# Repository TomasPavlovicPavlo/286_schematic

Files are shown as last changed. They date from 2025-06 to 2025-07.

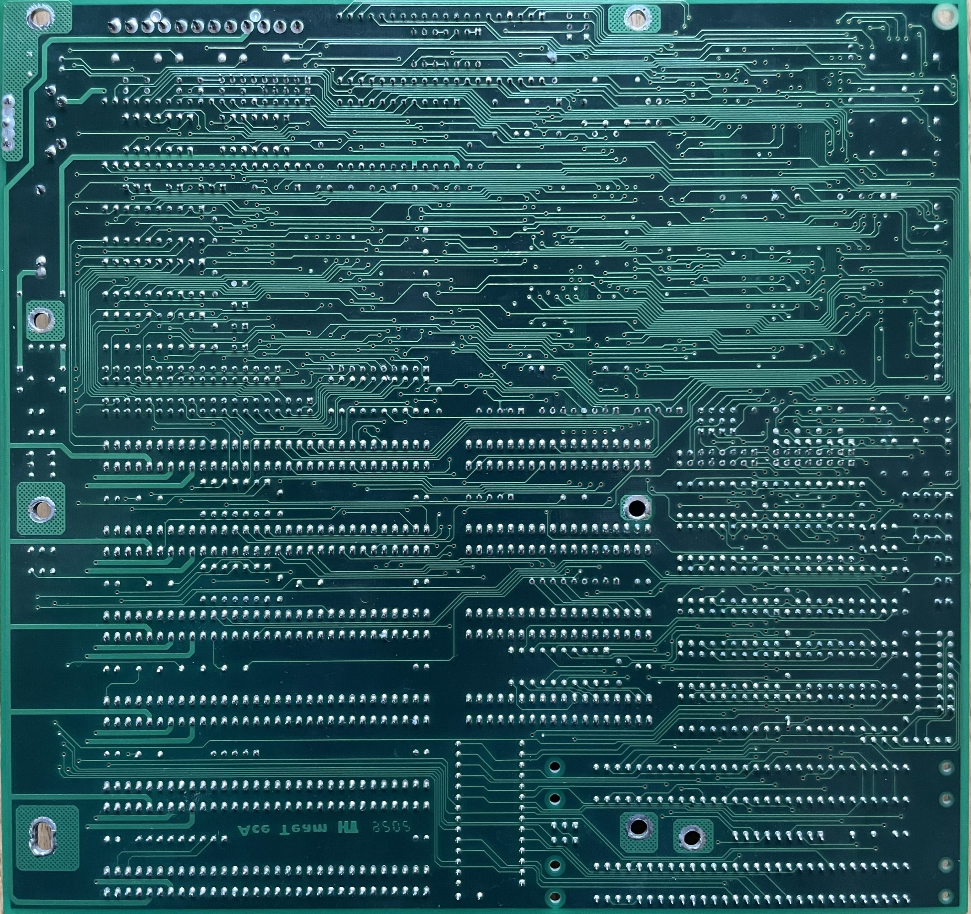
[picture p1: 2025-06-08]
KiCAD/bot.JPG

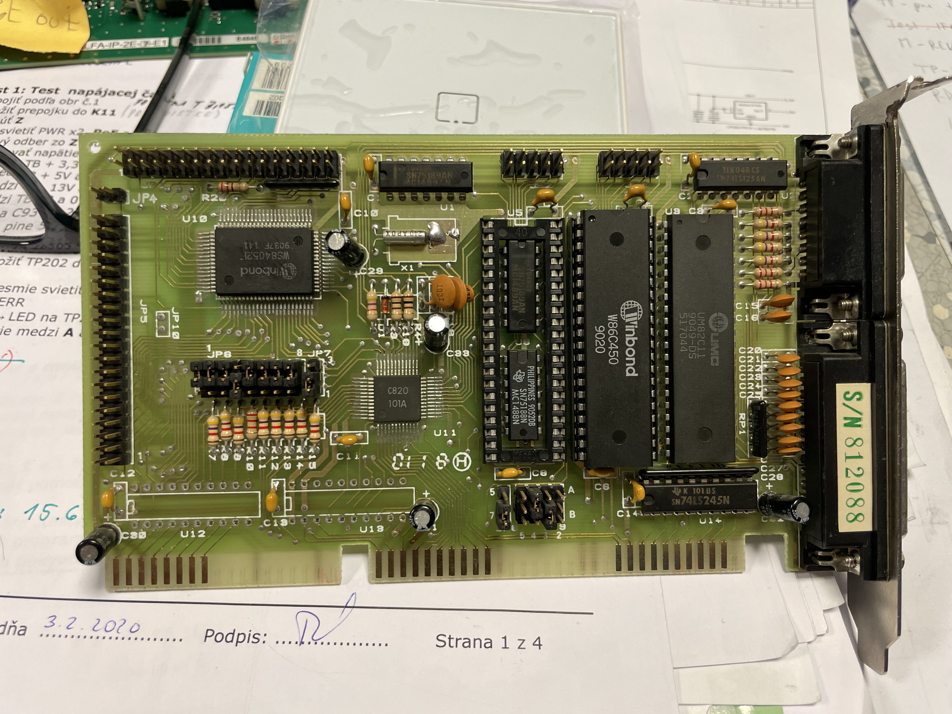
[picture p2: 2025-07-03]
IDE_controller/IMG_6849.JPG

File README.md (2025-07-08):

## Reverse engineering of 286 motherboard
This is the repository vhere I am working on reverse engineering of one 286 motherboard. It is still in progress. I use KiCad. In the PCB editor I insert fotos as background image and draw all tracks. Then I transfer all to schematic and analyse connections.

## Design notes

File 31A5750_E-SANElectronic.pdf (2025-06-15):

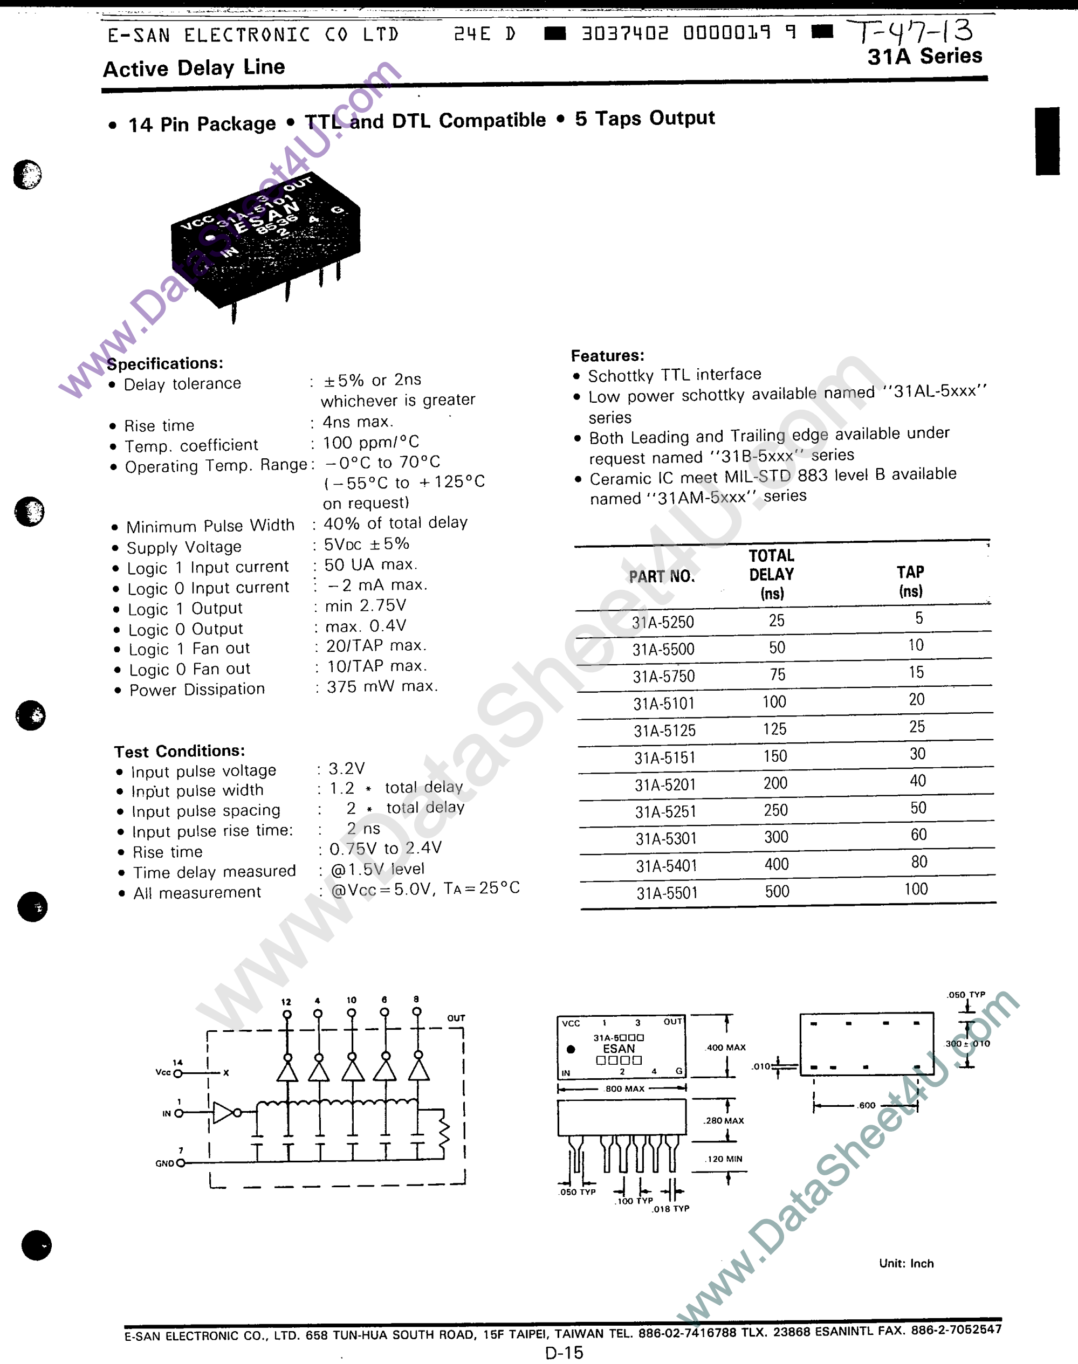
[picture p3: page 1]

www.DataSheet4U.com www.DataSheet4U.com www.DataSheet4U.com

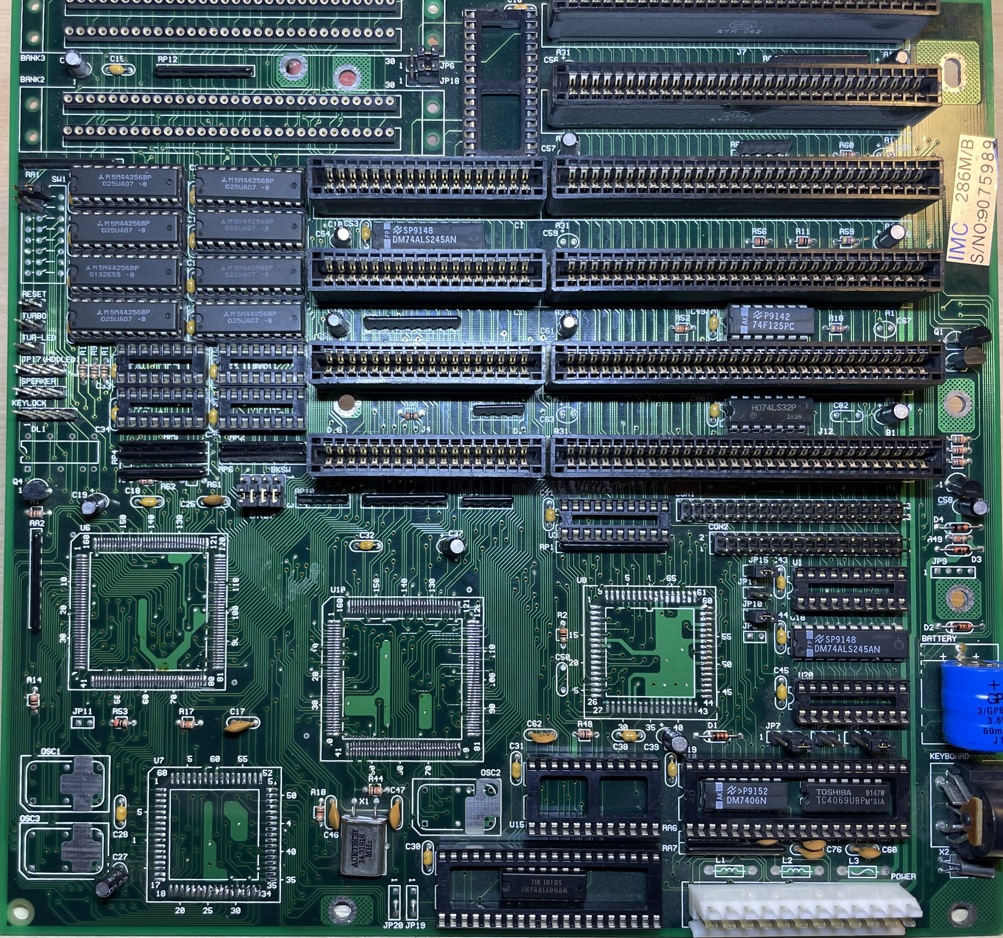
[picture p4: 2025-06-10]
KiCAD/top2.jpg

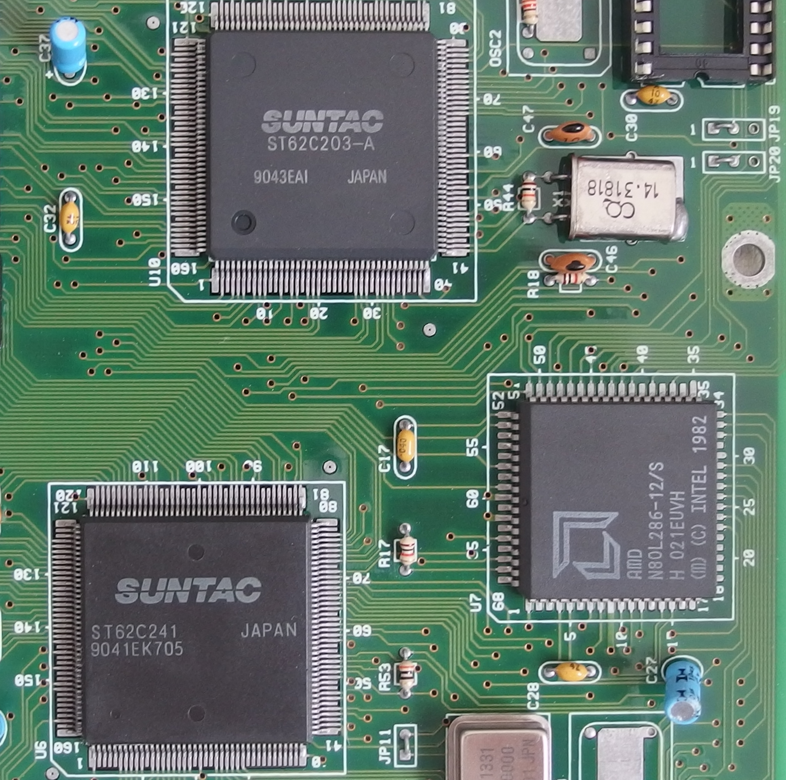
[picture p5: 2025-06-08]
KiCAD/suntac-286p-chipset-6633c39411f69253882697.jpg

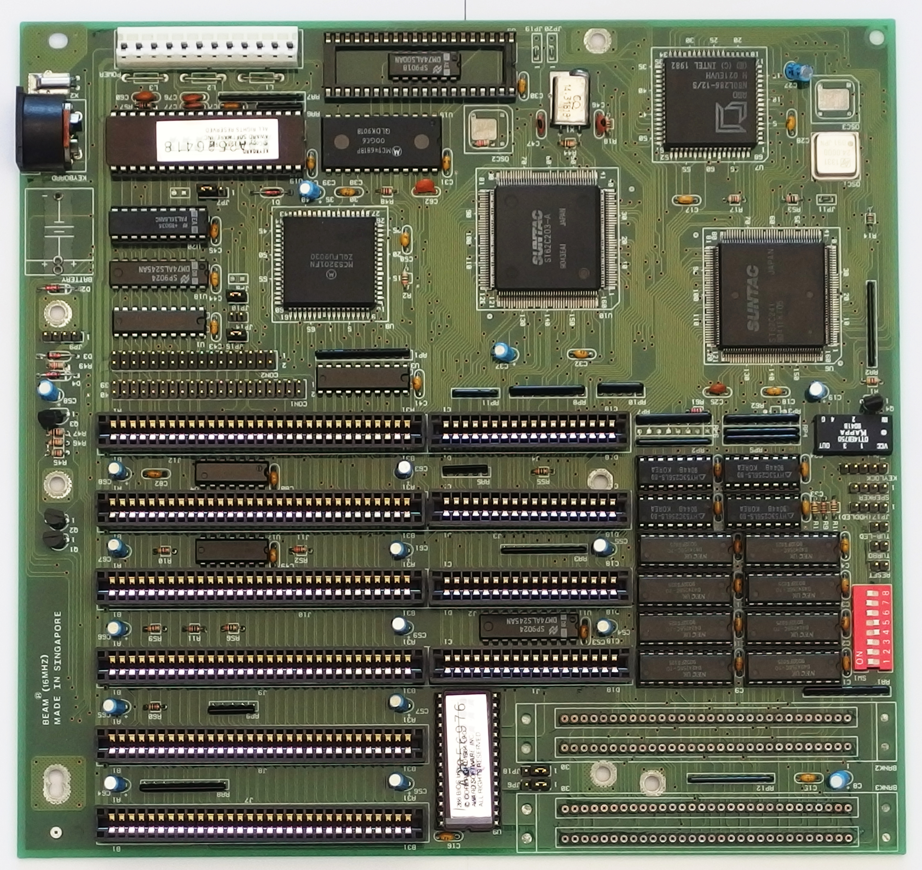
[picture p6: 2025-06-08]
KiCAD/suntac-286p-front-6633c394108ce740753764.jpg

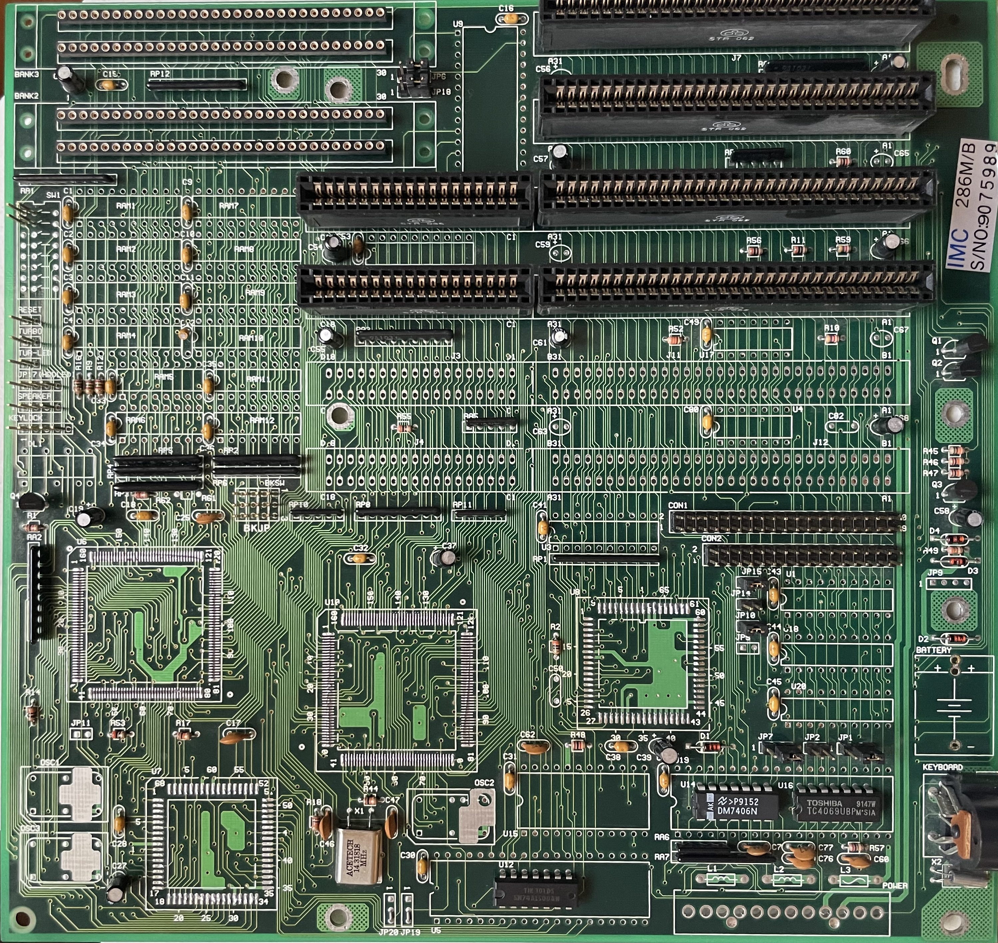
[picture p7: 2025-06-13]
KiCAD/top3.jpg

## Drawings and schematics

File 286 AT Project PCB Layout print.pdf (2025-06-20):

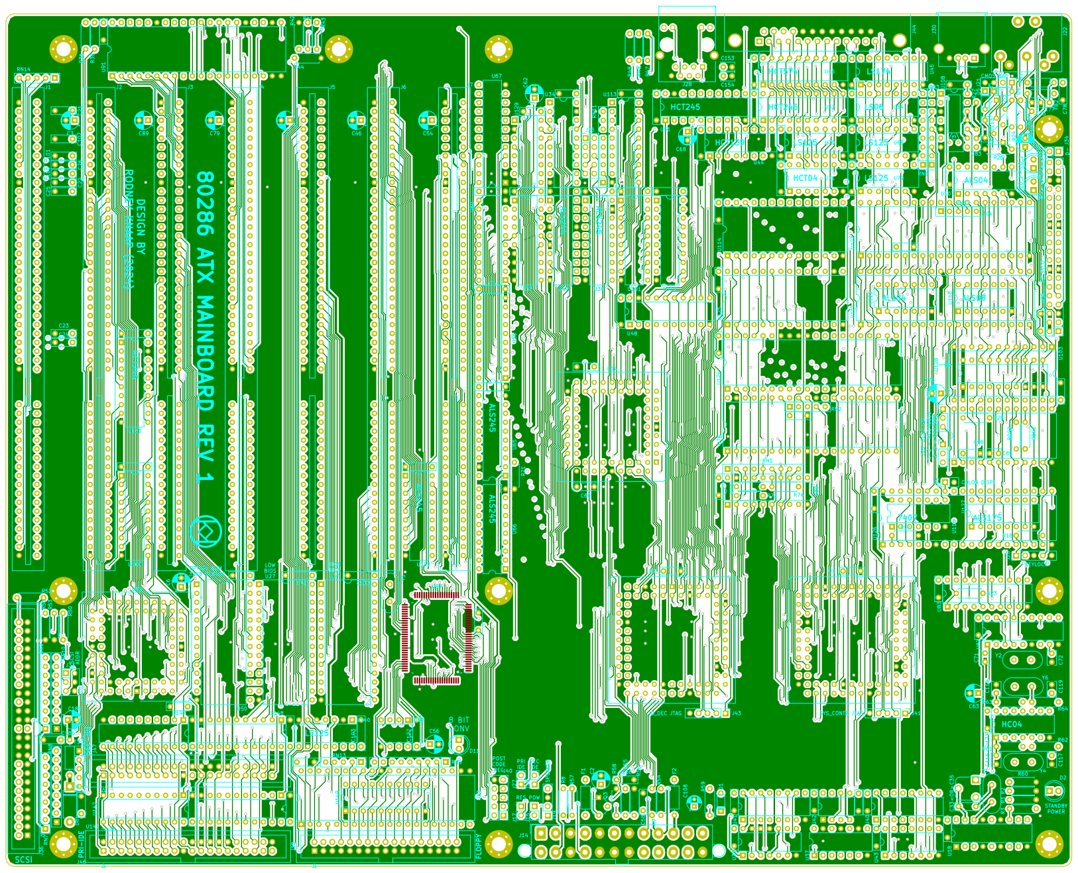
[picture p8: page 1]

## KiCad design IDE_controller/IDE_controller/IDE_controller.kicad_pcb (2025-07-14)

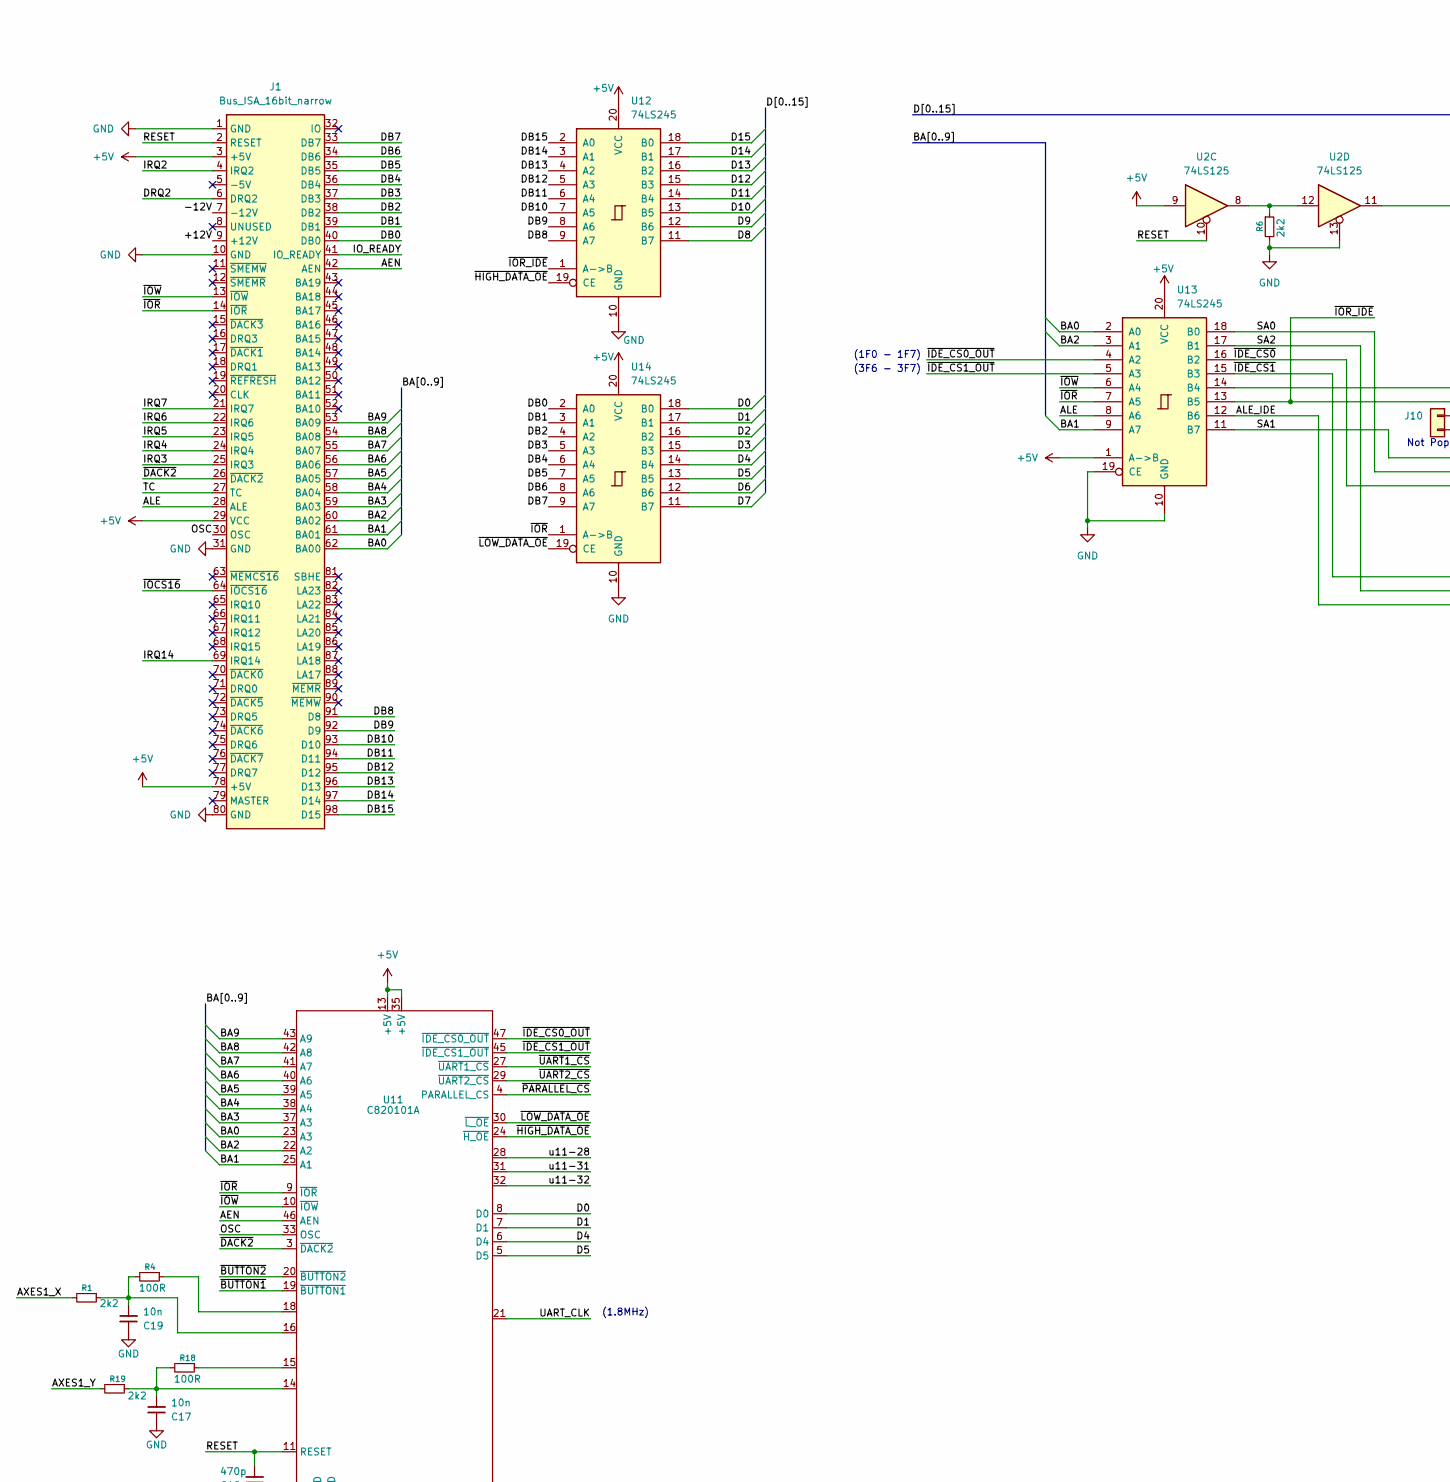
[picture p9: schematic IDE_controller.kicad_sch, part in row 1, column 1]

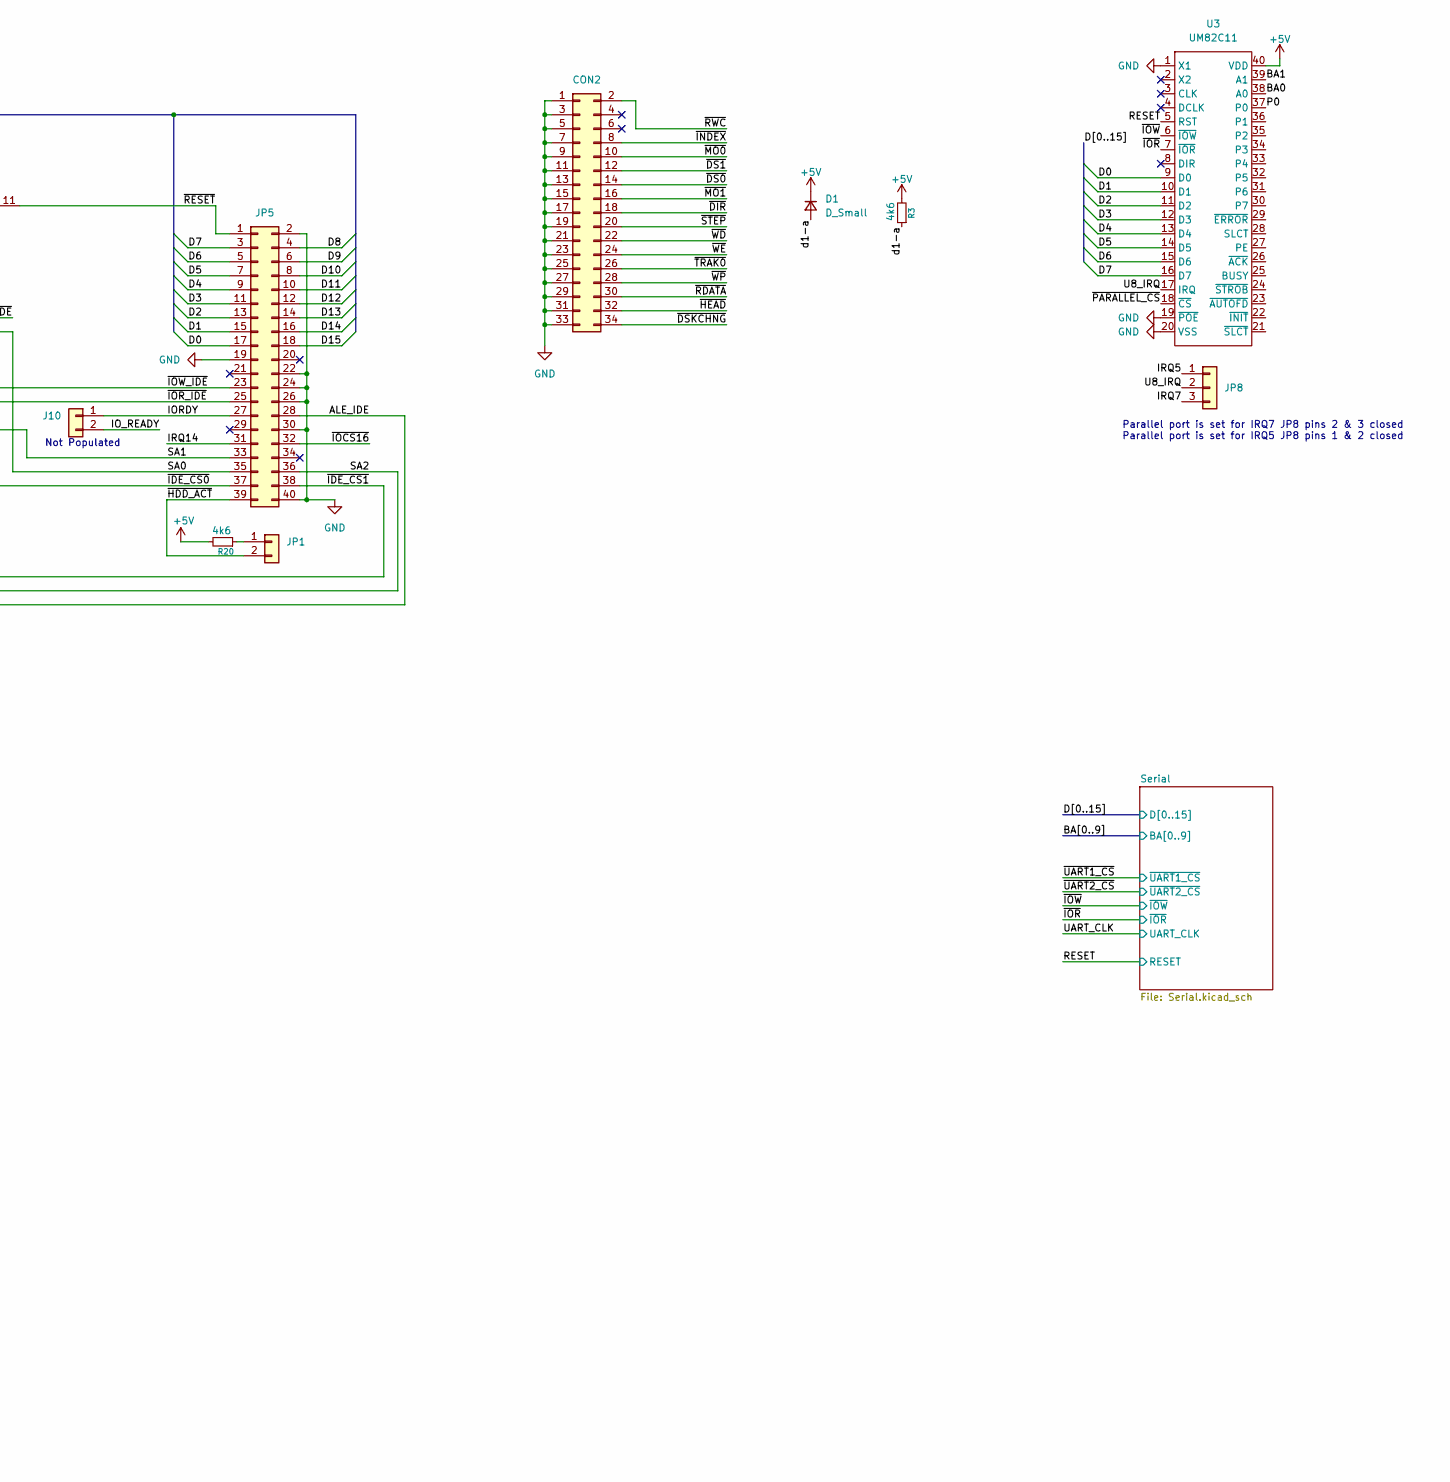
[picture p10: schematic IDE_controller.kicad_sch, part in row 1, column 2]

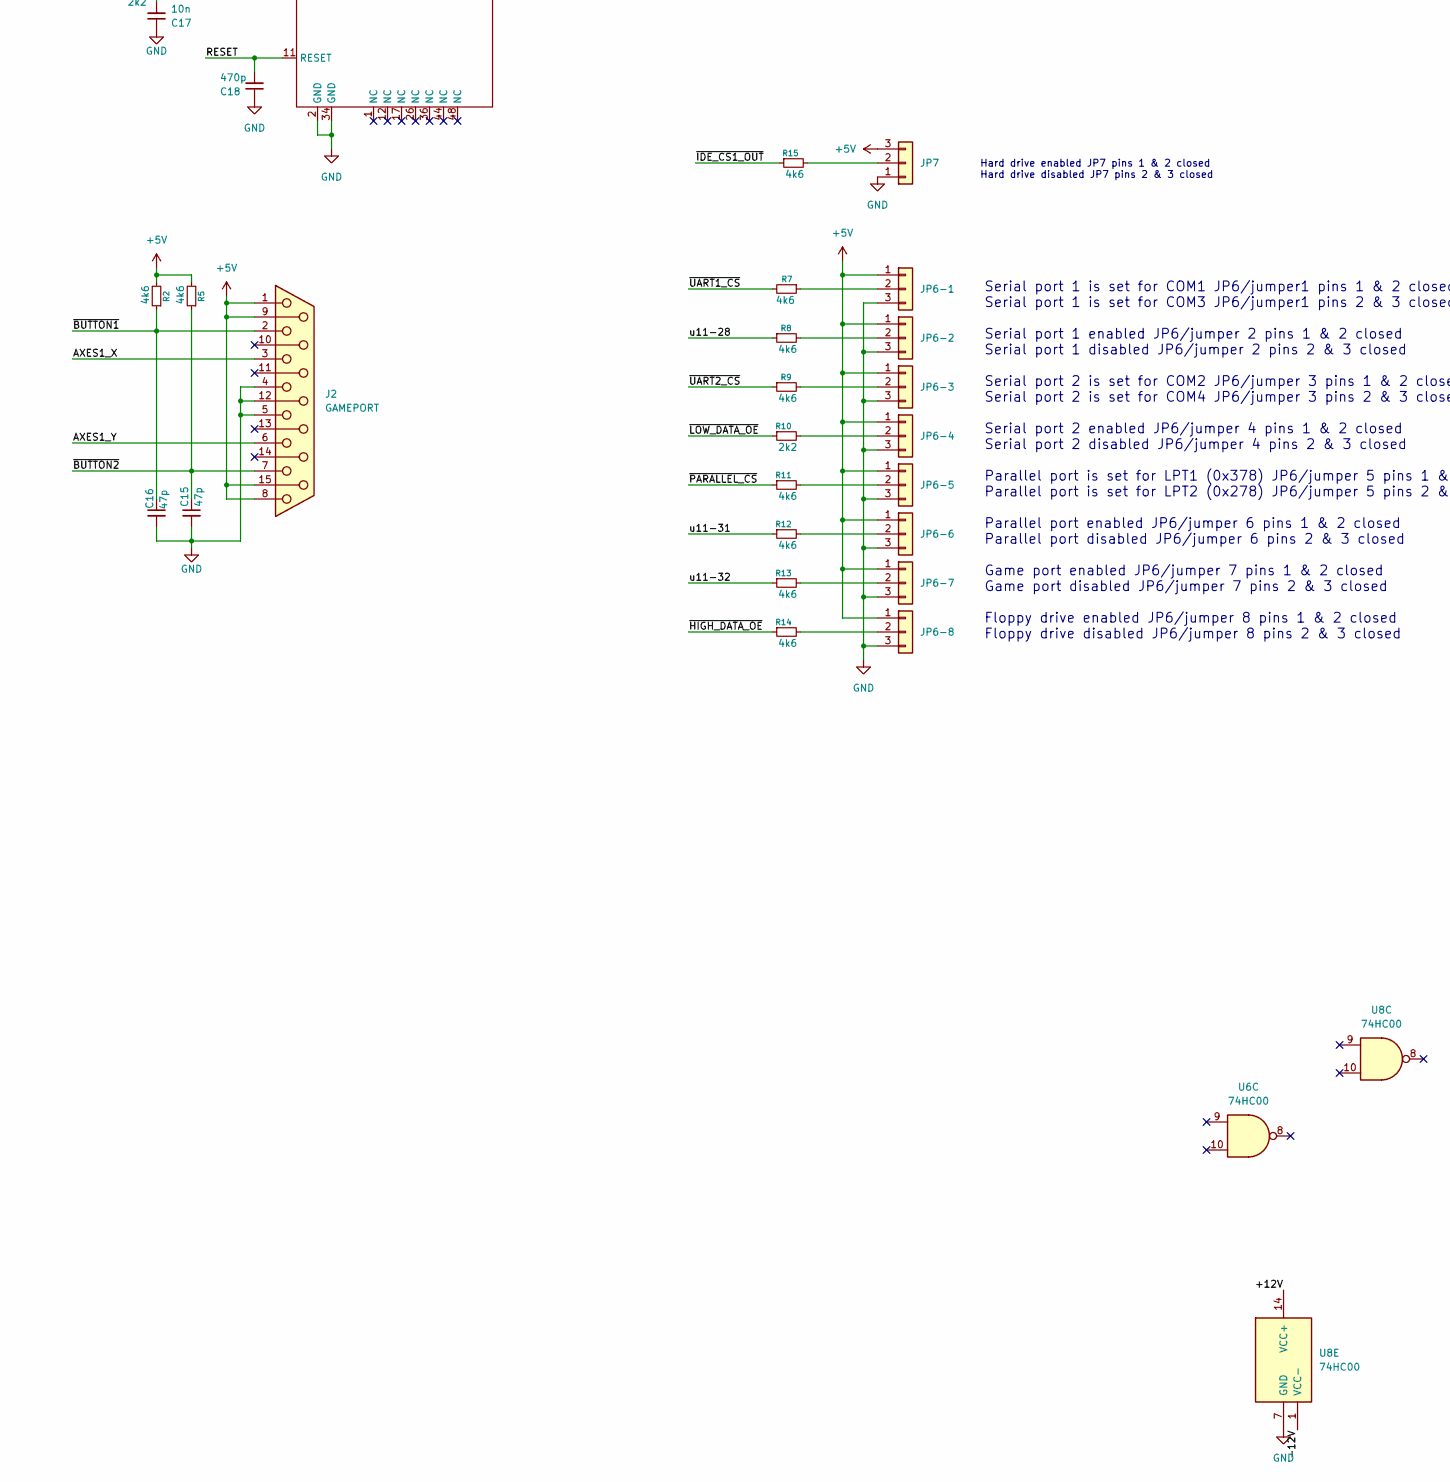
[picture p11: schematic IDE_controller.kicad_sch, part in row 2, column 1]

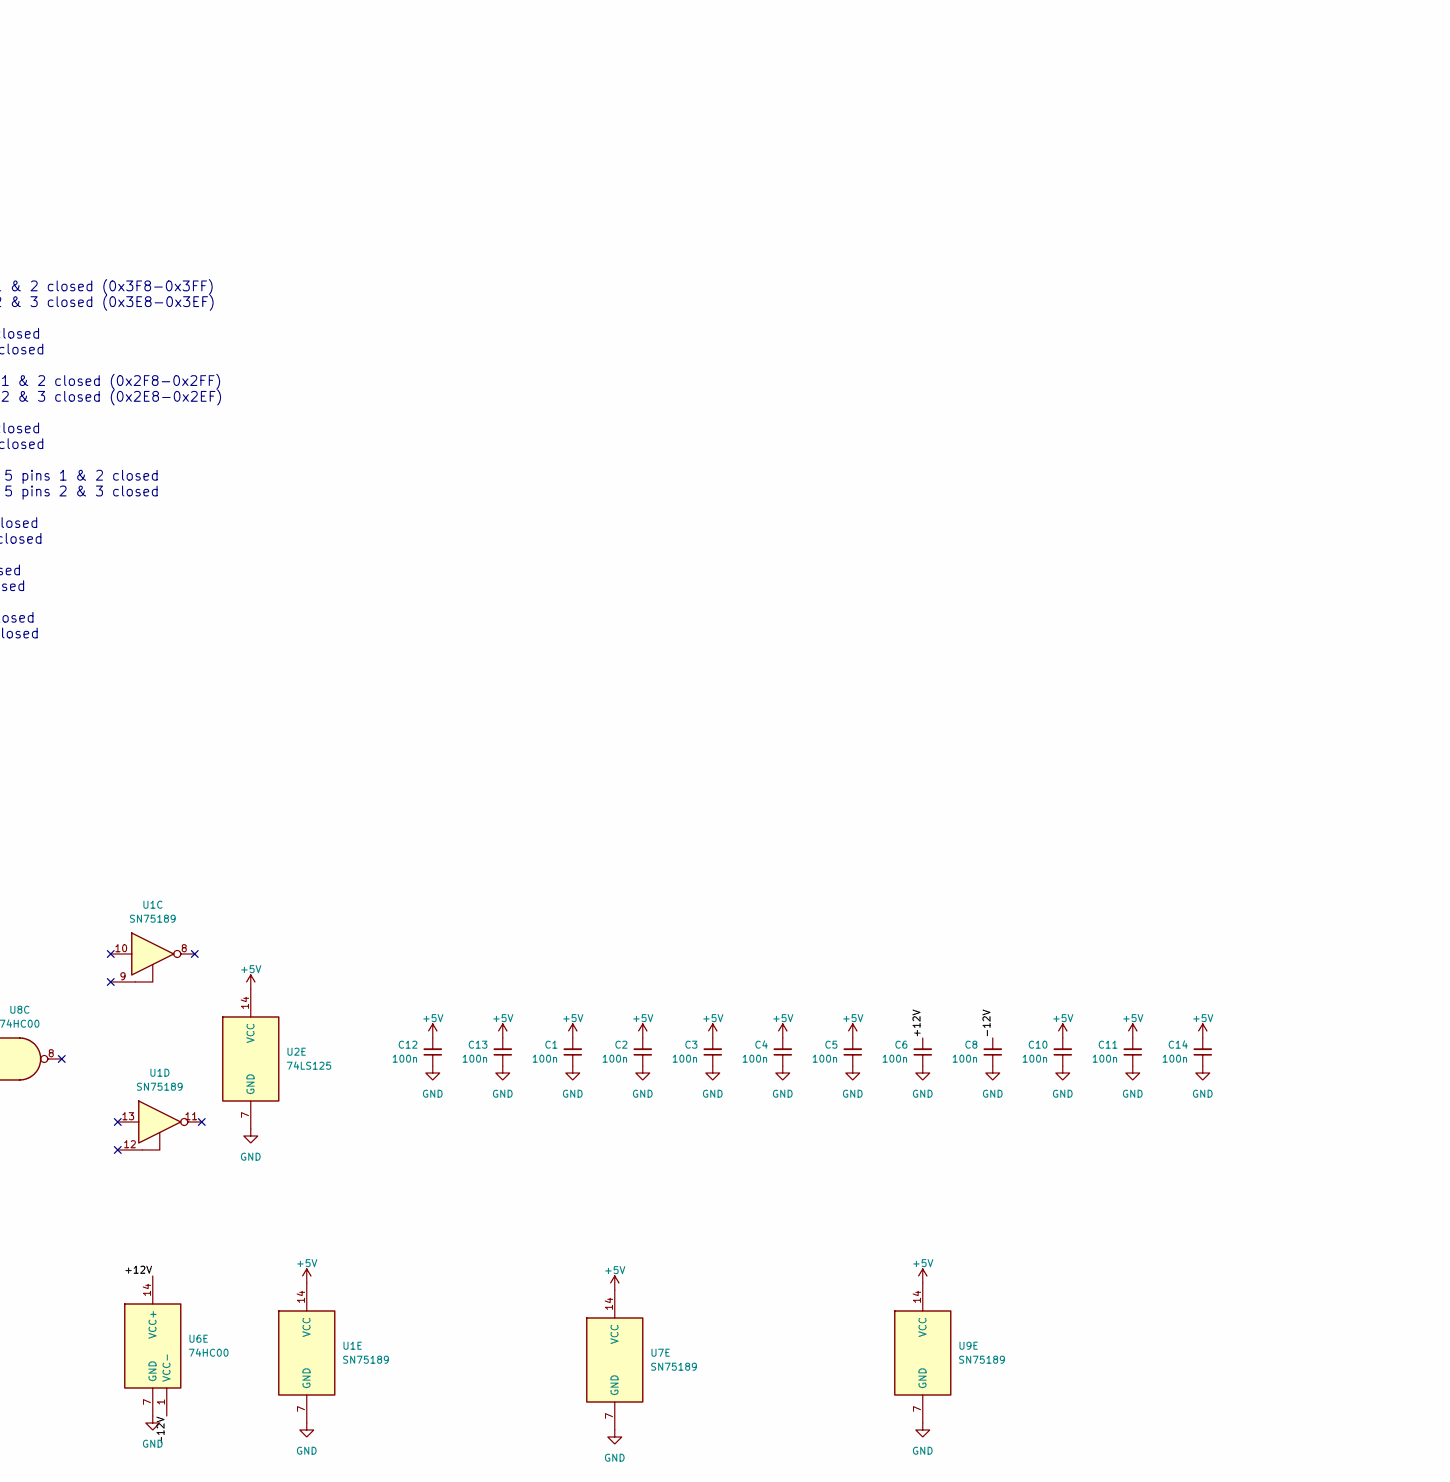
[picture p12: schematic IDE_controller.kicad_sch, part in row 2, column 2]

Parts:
C1, C2, C3, C4, C5, C6, C8, C10, C11, C12, C13, C14: 100n; C_Disc_D4.3mm_W1.9mm_P5.00mm
C15, C16: 47p; C_Disc_D4.3mm_W1.9mm_P5.00mm
C17, C19: 10n; C_Disc_D4.3mm_W1.9mm_P5.00mm
C18: 470p; C_Disc_D4.3mm_W1.9mm_P5.00mm
CON2: Conn_02x17_Odd_Even; PinHeader_2x17_P2.54mm_Vertical
D1: D_Small; D_A-405_P10.16mm_Horizontal
J1: Bus_ISA_16bit_narrow; BUS_AT
J2: GAMEPORT; DSUB-15_Socket_Horizontal_P2.77x2.54mm_EdgePinOffset9.40mm
J10: Conn_01x02; PinHeader_1x02_P2.54mm_Vertical
JP1: Conn_01x02; PinHeader_1x02_P2.54mm_Vertical
JP5: Conn_02x20_Odd_Even; PinHeader_2x20_P2.54mm_Vertical
JP6-1, JP6-2, JP6-3, JP6-4, JP6-5, JP6-6, JP6-7, JP6-8, JP7, JP8: Conn_01x03; PinHeader_1x03_P2.54mm_Vertical
R1, R6, R10, R19: 2k2; R_Axial_DIN0207_L6.3mm_D2.5mm_P10.16mm_Horizontal
R2, R3, R5, R7, R8, R9, R11, R12, R13, R14, R15, R20: 4k6; R_Axial_DIN0207_L6.3mm_D2.5mm_P10.16mm_Horizontal
R4, R18: 100R; R_Axial_DIN0207_L6.3mm_D2.5mm_P10.16mm_Horizontal
U1, U7, U9: SN75189; DIP-14_W7.62mm
U2: 74LS125; DIP-14_W7.62mm
U3: UM82C11; DIP-40_W15.24mm
U6, U8: 74HC00; DIP-14_W7.62mm
U11: C820101A; LQFP-48_10x10mm_P0.7mm
U12, U13, U14: 74LS245; DIP-20_W7.62mm

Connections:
+5V: C1.2, C2.2, C3.2, C4.2, C5.2, C10.2, C11.2, C12.2, C13.2, C14.2, D1.1 (K), J1.3 (+5V), J1.29 (VCC), J1.78 (+5V), J2.1, J2.8, J2.9, J2.15, JP6-1.1, JP6-2.1, JP6-3.1, JP6-4.1, JP6-5.1, JP6-6.1, JP6-7.1, JP6-8.1, JP7.3, R2.2, R3.2, R5.2, R20.2, U1.14 (VCC), U2.9, U2.14 (VCC), U3.40 (VDD), U7.14 (VCC), U9.14 (VCC), U11.13 (+5V), U11.35 (+5V), U12.20 (VCC), U13.1 (A->B), U13.20 (VCC), U14.20 (VCC); also elsewhere on the board
/+12V: C6.2, J1.9 (+12V), U6.14 (VCC+), U8.14 (VCC+)
/-12V: C8.2, J1.7 (-12V), U6.1 (VCC-), U8.1 (VCC-)
/AEN: J1.42 (AEN), U11.46 (AEN)
/ALE: J1.28 (ALE), U13.8 (A6)
/ALE_IDE: JP5.28, U13.12 (B6)
/AXES1_X: J2.3, R1.2
/AXES1_Y: J2.6, R19.2
/BA0: J1.62 (BA00), U3.38 (A0), U11.23 (A3), U13.2 (A0); also elsewhere on the board
/BA1: J1.61 (BA01), U3.39 (A1), U11.25 (A1), U13.9 (A7); also elsewhere on the board
/BA2: J1.60 (BA02), U11.22 (A2), U13.3 (A1); also elsewhere on the board
/BA3: J1.59 (BA03), U11.37 (A3)
/BA4: J1.58 (BA04), U11.38 (A4)
/BA5: J1.57 (BA05), U11.39 (A5)
/BA6: J1.56 (BA06), U11.40 (A6)
/BA7: J1.55 (BA07), U11.41 (A7)
/BA8: J1.54 (BA08), U11.42 (A8)
/BA9: J1.53 (BA09), U11.43 (A9)
/D0: JP5.17, U3.9 (D0), U11.8 (D0), U14.18 (B0); also elsewhere on the board
/D1: JP5.15, U3.10 (D1), U11.7 (D1), U14.17 (B1); also elsewhere on the board
/D2: JP5.13, U3.11 (D2), U14.16 (B2); also elsewhere on the board
/D3: JP5.11, U3.12 (D3), U14.15 (B3); also elsewhere on the board
/D4: JP5.9, U3.13 (D4), U11.6 (D4), U14.14 (B4); also elsewhere on the board
/D5: JP5.7, U3.14 (D5), U11.5 (D5), U14.13 (B5); also elsewhere on the board
/D6: JP5.5, U3.15 (D6), U14.12 (B6); also elsewhere on the board
/D7: JP5.3, U3.16 (D7), U14.11 (B7); also elsewhere on the board
/D8: JP5.4, U12.11 (B7)
/D9: JP5.6, U12.12 (B6)
/D10: JP5.8, U12.13 (B5)
/D11: JP5.10, U12.14 (B4)
/D12: JP5.12, U12.15 (B3)
/D13: JP5.14, U12.16 (B2)
/D14: JP5.16, U12.17 (B1)
/D15: JP5.18, U12.18 (B0)
/DB0: J1.40 (DB0), U14.2 (A0)
/DB1: J1.39 (DB1), U14.3 (A1)
/DB2: J1.38 (DB2), U14.4 (A2)
/DB3: J1.37 (DB3), U14.5 (A3)
/DB4: J1.36 (DB4), U14.6 (A4)
/DB5: J1.35 (DB5), U14.7 (A5)
/DB6: J1.34 (DB6), U14.8 (A6)
/DB7: J1.33 (DB7), U14.9 (A7)
/DB8: J1.91 (D8), U12.9 (A7)
/DB9: J1.92 (D9), U12.8 (A6)
/DB10: J1.93 (D10), U12.7 (A5)
/DB11: J1.94 (D11), U12.6 (A4)
/DB12: J1.95 (D12), U12.5 (A3)
/DB13: J1.96 (D13), U12.4 (A2)
/DB14: J1.97 (D14), U12.3 (A1)
/DB15: J1.98 (D15), U12.2 (A0)
/DRQ2: J1.6 (DRQ2)
/IORDY: J10.1, JP5.27
/IO_READY: J1.41 (IO_READY), J10.2
/IRQ6: J1.22 (IRQ6)
/IRQ7: J1.21 (IRQ7), JP8.3
/IRQ14: J1.69 (IRQ14), JP5.31
/OSC: J1.30 (OSC), U11.33 (OSC)
/P0: U3.37 (P0)
/RESET: C18.2, J1.2 (RESET), U2.10, U3.5 (RST), U11.11 (RESET); also elsewhere on the board
/SA0: JP5.35, U13.18 (B0)
/SA1: JP5.33, U13.11 (B7)
/SA2: JP5.36, U13.17 (B1)
/TC: J1.27 (TC)
/U8_IRQ: JP8.2, U3.17 (IRQ)
/UART_CLK: U11.21; also elsewhere on the board
/d1-a: D1.2 (A), R3.1
/u11-28: R8.1, U11.28
/u11-31: R12.1, U11.31
/u11-32: R13.1, U11.32
/~BUTTON1: C16.1, J2.2, R2.1, U11.19 (~BUTTON1)
/~BUTTON2: C15.1, J2.7, R5.1, U11.20 (~BUTTON2)
/~DACK2: J1.26 (~DACK2), U11.3 (~DACK2)
/~DIR: CON2.18
/~DS0: CON2.14
/~DS1: CON2.12
/~DSKCHNG: CON2.34
/~HDD_ACT: JP1.2, JP5.39
/~HEAD: CON2.32
/~HIGH_DATA_OE: R14.1, U11.24 (~H_OE), U12.19 (CE)
/~IDE_CS0_OUT: U11.47 (~IDE_CS0_OUT), U13.4 (A2)
/~IDE_CS0: JP5.37, U13.16 (B2)
/~IDE_CS1_OUT: R15.1, U11.45 (~IDE_CS1_OUT), U13.5 (A3)
/~IDE_CS1: JP5.38, U13.15 (B3)
/~INDEX: CON2.8
/~IOCS16: J1.64 (~IOCS16), JP5.32
/~IOR_IDE: JP5.25, U12.1 (A->B), U13.13 (B5)
/~IOR: J1.14 (~IOR), U3.7 (~IOR), U11.9 (~IOR), U13.7 (A5), U14.1 (A->B); also elsewhere on the board
/~IOW_IDE: JP5.23, U13.14 (B4)
/~IOW: J1.13 (~IOW), U3.6 (~IOW), U11.10 (~IOW), U13.6 (A4); also elsewhere on the board
/~LOW_DATA_OE: R10.1, U11.30 (~L_OE), U14.19 (CE)
/~MO0: CON2.10
/~MO1: CON2.16
/~PARALLEL_CS: R11.1, U3.18 (~CS), U11.4 (PARALLEL_CS)
/~RDATA: CON2.30
/~RESET: JP5.1, U2.11
/~RWC: CON2.2
/~STEP: CON2.20
/~TRAK0: CON2.26
/~UART1_CS: R7.2, U11.27 (~UART1_CS); also elsewhere on the board
/~UART2_CS: R9.1, U11.29 (~UART2_CS); also elsewhere on the board
/~WD: CON2.22
/~WE: CON2.24
/~WP: CON2.28
GND: C1.1, C2.1, C3.1, C4.1, C5.1, C6.1, C8.1, C10.1, C11.1, C12.1, C13.1, C14.1, C15.2, C16.2, C17.1, C18.1, C19.1, CON2.1, CON2.3, CON2.5, CON2.7, CON2.9, CON2.11, CON2.13, CON2.15, CON2.17, CON2.19, CON2.21, CON2.23, CON2.25, CON2.27, CON2.29, CON2.31, CON2.33, J1.1 (GND), J1.10 (GND), J1.31 (GND), J1.80 (GND), J2.4, J2.5, J2.12, JP5.2, JP5.19, JP5.22, JP5.24, JP5.26, JP5.30, JP5.40, JP6-1.3, JP6-2.3, JP6-3.3, JP6-4.3, JP6-5.3, JP6-6.3, JP6-7.3, JP6-8.3, JP7.1, R6.2, U1.7 (GND), U2.7 (GND), U2.13, U3.1 (X1), U3.19 (~POE), U3.20 (VSS), U6.7 (GND), U7.7 (GND), U8.7 (GND), U9.7 (GND), U11.2 (GND), U11.34 (GND), U12.10 (GND), U13.10 (GND), U13.19 (CE), U14.10 (GND); also elsewhere on the board
IRQ2: J1.4 (IRQ2); also elsewhere on the board
IRQ3: J1.25 (IRQ3); also elsewhere on the board
IRQ4: J1.24 (IRQ4); also elsewhere on the board
IRQ5: J1.23 (IRQ5), JP8.1; also elsewhere on the board
unnamed: C17.2, R18.2, R19.1, U11.14
unnamed: C19.2, R1.1, R4.2, U11.16
unnamed: JP1.1, R20.1
unnamed: JP6-1.2, R7.1
unnamed: JP6-2.2, R8.2
unnamed: JP6-3.2, R9.2
unnamed: JP6-4.2, R10.2
unnamed: JP6-5.2, R11.2
unnamed: JP6-6.2, R12.2
unnamed: JP6-7.2, R13.2
unnamed: JP6-8.2, R14.2
unnamed: JP7.2, R15.2
unnamed: R4.1, U11.18
unnamed: R6.1, U2.8, U2.12
unnamed: R18.1, U11.15

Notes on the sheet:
(3F6 - 3F7)
Not Populated
Serial port 1 is set for COM1 JP6/jumper1 pins 1 & 2 closed (0x3F8-0x3FF) Serial port 1 is set for COM3 JP6/jumper1 pins 2 & 3 closed (0x3E8-0x3EF) Serial port 1 enabled JP6/jumper 2 pins 1 & 2 closed Serial port 1 disabled JP6/jumper 2 pins 2 & 3 closed Serial port 2 is set for COM2 JP6/jumper 3 p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
(1.8MHz)
Parallel port is set for IRQ7 JP8 pins 2 & 3 closed Parallel port is set for IRQ5 JP8 pins 1 & 2 closed
(1F0 - 1F7)
Hard drive enabled JP7 pins 1 & 2 closed Hard drive disabled JP7 pins 2 & 3 closed

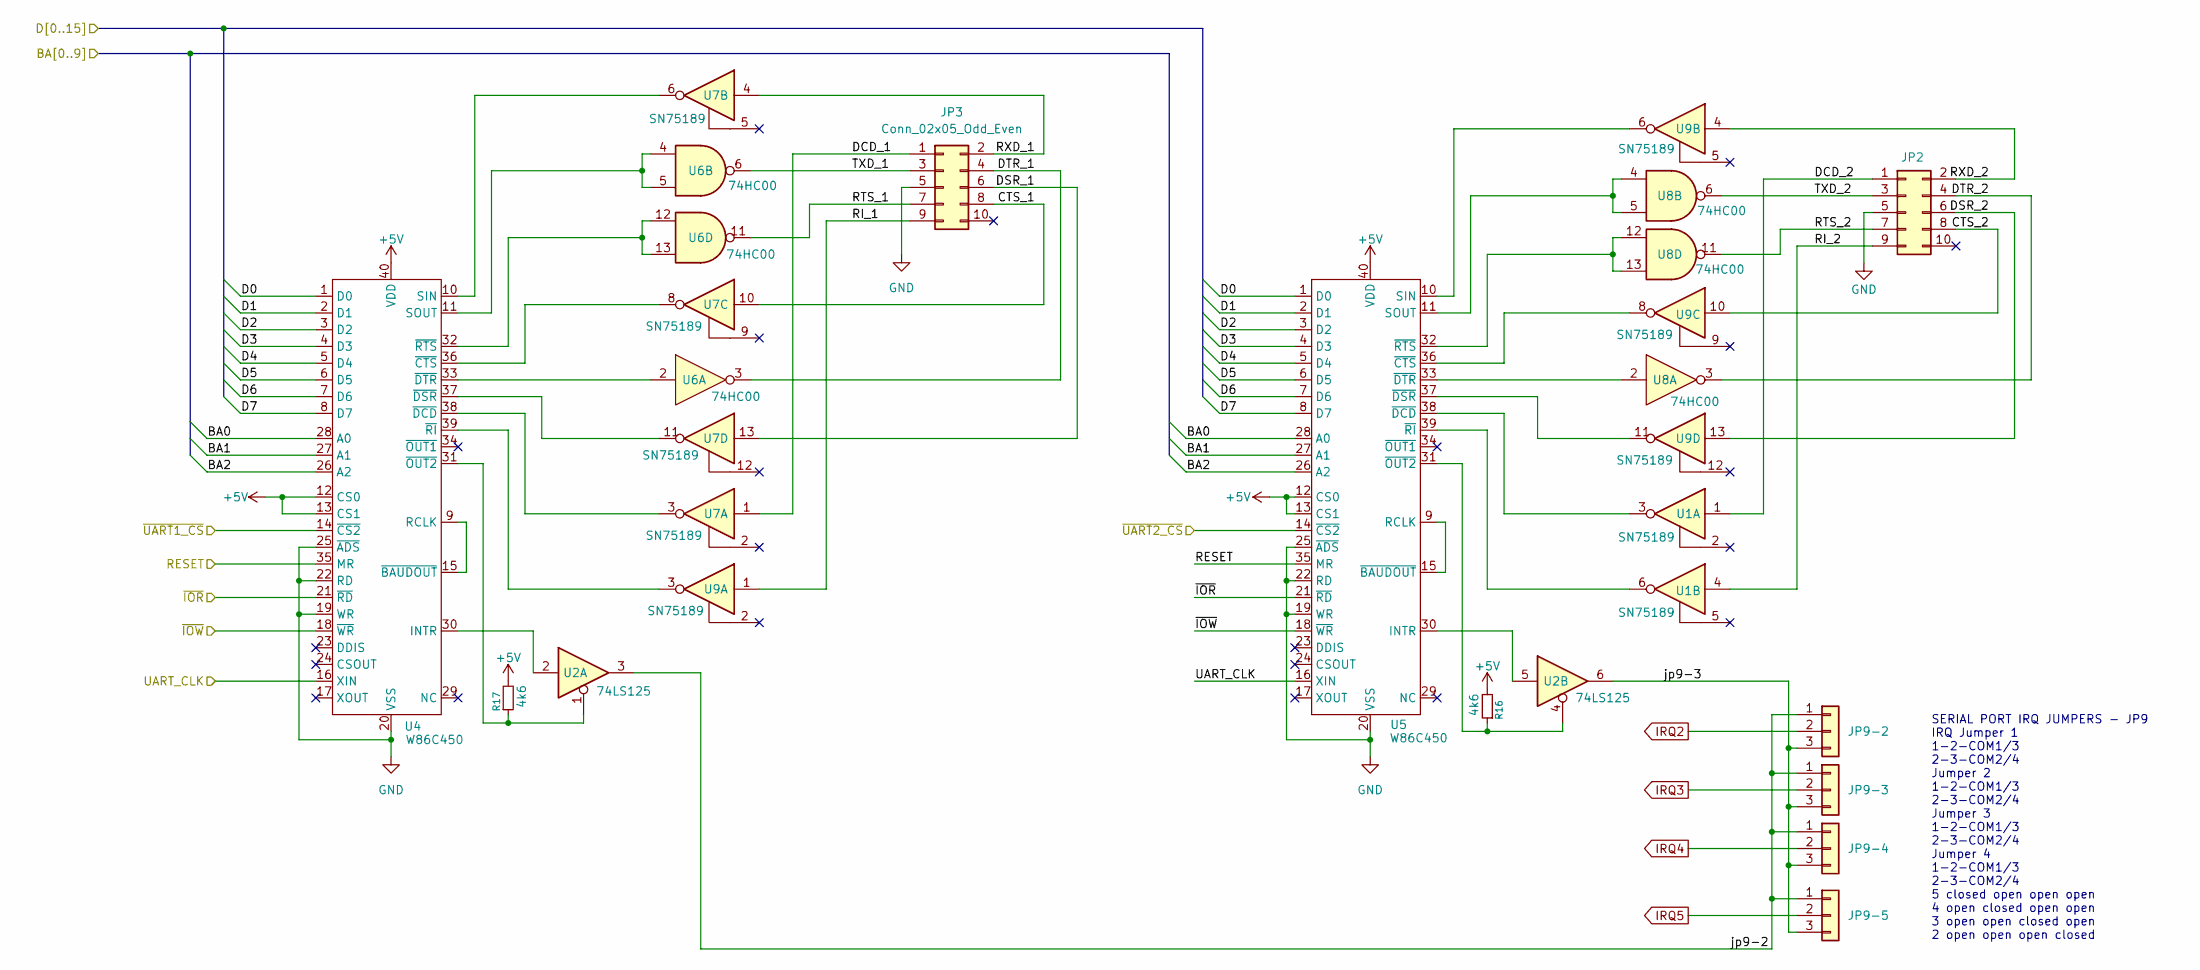
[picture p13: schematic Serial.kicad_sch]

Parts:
JP2, JP3: Conn_02x05_Odd_Even; PinHeader_2x05_P2.54mm_Vertical
JP9-2, JP9-3, JP9-4, JP9-5: Conn_01x03; PinHeader_1x03_P2.54mm_Vertical
R16, R17: 4k6; R_Axial_DIN0207_L6.3mm_D2.5mm_P10.16mm_Horizontal
U1, U7, U9: SN75189; DIP-14_W7.62mm
U2: 74LS125; DIP-14_W7.62mm
U4, U5: W86C450; DIP-40_W15.24mm_Socket
U6, U8: 74HC00; DIP-14_W7.62mm

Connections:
+5V: R16.2, R17.2, U4.12 (CS0), U4.13 (CS1), U4.40 (VDD), U5.12 (CS0), U5.13 (CS1), U5.40 (VDD); also elsewhere on the board
/BA0: U4.28 (A0), U5.28 (A0); also elsewhere on the board
/BA1: U4.27 (A1), U5.27 (A1); also elsewhere on the board
/BA2: U4.26 (A2), U5.26 (A2); also elsewhere on the board
/D0: U4.1 (D0), U5.1 (D0); also elsewhere on the board
/D1: U4.2 (D1), U5.2 (D1); also elsewhere on the board
/D2: U4.3 (D2), U5.3 (D2); also elsewhere on the board
/D3: U4.4 (D3), U5.4 (D3); also elsewhere on the board
/D4: U4.5 (D4), U5.5 (D4); also elsewhere on the board
/D5: U4.6 (D5), U5.6 (D5); also elsewhere on the board
/D6: U4.7 (D6), U5.7 (D6); also elsewhere on the board
/D7: U4.8 (D7), U5.8 (D7); also elsewhere on the board
/RESET: U4.35 (MR), U5.35 (MR); also elsewhere on the board
/Serial/CTS_1: JP3.8, U7.10
/Serial/CTS_2: JP2.8, U9.10
/Serial/DCD_1: JP3.1, U7.1
/Serial/DCD_2: JP2.1, U1.1
/Serial/DSR_1: JP3.6, U7.13
/Serial/DSR_2: JP2.6, U9.13
/Serial/DTR_1: JP3.4, U6.3
/Serial/DTR_2: JP2.4, U8.3
/Serial/RI_1: JP3.9, U9.1
/Serial/RI_2: JP2.9, U1.4
/Serial/RTS_1: JP3.7, U6.11
/Serial/RTS_2: JP2.7, U8.11
/Serial/RXD_1: JP3.2, U7.4
/Serial/RXD_2: JP2.2, U9.4
/Serial/TXD_1: JP3.3, U6.6
/Serial/TXD_2: JP2.3, U8.6
/Serial/jp9-2: JP9-2.1, JP9-3.1, JP9-4.1, JP9-5.1, U2.3
/Serial/jp9-3: JP9-2.3, JP9-3.3, JP9-4.3, JP9-5.3, U2.6
/UART_CLK: U4.16 (XIN), U5.16 (XIN); also elsewhere on the board
/~IOR: U4.21 (~RD), U5.21 (~RD); also elsewhere on the board
/~IOW: U4.18 (~WR), U5.18 (~WR); also elsewhere on the board
/~UART1_CS: U4.14 (~CS2); also elsewhere on the board
/~UART2_CS: U5.14 (~CS2); also elsewhere on the board
GND: JP2.5, JP3.5, U4.19 (WR), U4.20 (VSS), U4.22 (RD), U4.25 (~ADS), U5.19 (WR), U5.20 (VSS), U5.22 (RD), U5.25 (~ADS); also elsewhere on the board
IRQ2: JP9-2.2; also elsewhere on the board
IRQ3: JP9-3.2; also elsewhere on the board
IRQ4: JP9-4.2; also elsewhere on the board
IRQ5: JP9-5.2; also elsewhere on the board
unnamed: U2.2, U4.30 (INTR)
unnamed: U4.9 (RCLK), U4.15 (~BAUDOUT)
unnamed: U4.10 (SIN), U7.6
unnamed: U4.11 (SOUT), U6.4, U6.5
unnamed: U4.36 (~CTS), U7.8
unnamed: U4.38 (~DCD), U7.3
unnamed: U4.37 (~DSR), U7.11
unnamed: U4.33 (~DTR), U6.2
unnamed: R17.1, U2.1, U4.31 (~OUT2)
unnamed: U4.39 (~RI), U9.3
unnamed: U4.32 (~RTS), U6.12, U6.13
unnamed: U2.5, U5.30 (INTR)
unnamed: U5.9 (RCLK), U5.15 (~BAUDOUT)
unnamed: U5.10 (SIN), U9.6
unnamed: U5.11 (SOUT), U8.4, U8.5
unnamed: U5.36 (~CTS), U9.8
unnamed: U1.3, U5.38 (~DCD)
unnamed: U5.37 (~DSR), U9.11
unnamed: U5.33 (~DTR), U8.2
unnamed: R16.1, U2.4, U5.31 (~OUT2)
unnamed: U1.6, U5.39 (~RI)
unnamed: U5.32 (~RTS), U8.12, U8.13

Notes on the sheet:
SERIAL PORT IRQ JUMPERS - JP9 IRQ Jumper 1 1-2-COM1/3 2-3-COM2/4 Jumper 2 1-2-COM1/3 2-3-COM2/4 Jumper 3 1-2-COM1/3 2-3-COM2/4 Jumper 4 1-2-COM1/3 2-3-COM2/4 5 closed open open open 4 open closed open open 3 open open closed open 2 open open open closed

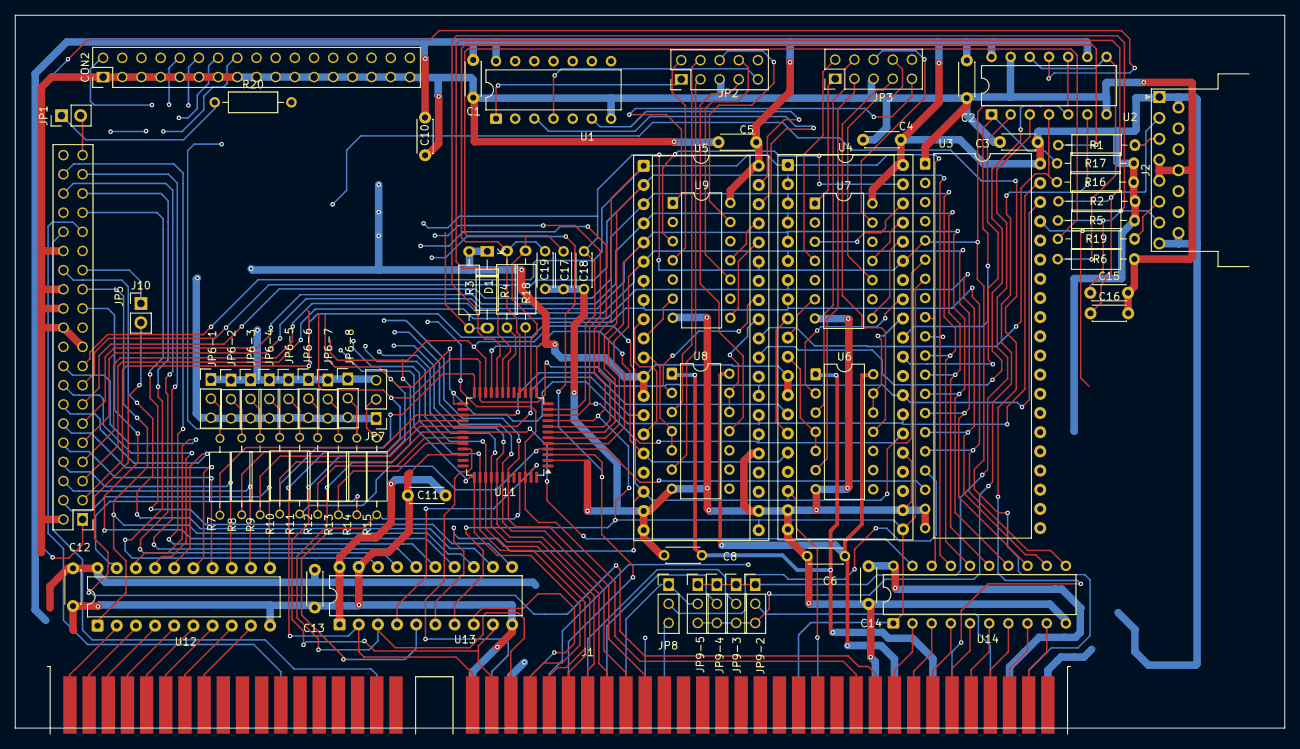
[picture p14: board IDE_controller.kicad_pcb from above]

Board: 2 copper layers, 168.1 x 94.4 mm, 73 parts (0 on the bottom side), 144 nets.

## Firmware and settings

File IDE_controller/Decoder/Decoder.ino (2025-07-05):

const int BA0 = 33;
const int BA1 = 22;
const int BA2 = 23;
const int BA3 = 24;
const int BA4 = 25;
const int BA5 = 26;
const int BA6 = 27;
const int BA7 = 28;
const int BA8 = 29;
const int BA9 = 30;
const int AEN = 31;
const int RESET = 34;
const int IOR = 35;

const int OUT4 = 32;
const int OUT3 = 36;
const int OUT2 = 37;
const int OUT1 = 38;
const int OUT0 = 39;


void setup()
{
  pinMode(BA0, OUTPUT);
  pinMode(BA1, OUTPUT);
  pinMode(BA2, OUTPUT);
  pinMode(BA3, OUTPUT);
  pinMode(BA4, OUTPUT);
  pinMode(BA5, OUTPUT);
  pinMode(BA6, OUTPUT);
  pinMode(BA7, OUTPUT);
  pinMode(BA8, OUTPUT);
  pinMode(BA9, OUTPUT);
  pinMode(AEN, OUTPUT);
  pinMode(RESET, OUTPUT);
  pinMode(IOR, OUTPUT);

  pinMode(OUT0, INPUT);
  pinMode(OUT1, INPUT);
  pinMode(OUT2, INPUT);
  pinMode(OUT3, INPUT);
  pinMode(OUT4, INPUT);

  digitalWrite(BA0, LOW);
  digitalWrite(BA1, LOW);
  digitalWrite(BA2, LOW);
  digitalWrite(BA3, LOW);
  digitalWrite(BA4, LOW);
  digitalWrite(BA5, LOW);
  digitalWrite(BA6, LOW);
  digitalWrite(BA7, LOW);
  digitalWrite(BA8, LOW);
  digitalWrite(BA9, LOW);
  digitalWrite(AEN, LOW);
  digitalWrite(RESET, LOW);
  digitalWrite(IOR, LOW);



  Serial.begin(115200);
  delay(3000);
  Serial.println("Radic CS decoder v0.0.0");

  digitalWrite(RESET, HIGH);
  delay(1000);
  digitalWrite(RESET, LOW);


  for(int i=0; i<=0x3FF; i++) {
    write_address(i);
    // Serial.println("0x" + String(i,HEX) + ": " + String(digitalRead(OUT0)) + ", " + String(digitalRead(OUT1)) + ", " + String(digitalRead(OUT2)) + ", " + String(digitalRead(OUT3)) + ", " + String(digitalRead(OUT4)));
    if(digitalRead(OUT4) == 1)  Serial.println("0x" + String(i,HEX) + ": 11111");
    else  Serial.println("0x" + String(i,HEX) + ": 0");
  }



}

void loop()
{
}

void write_address(int input) {

  if(input & 0x001) digitalWrite(BA0, HIGH);
  else  digitalWrite(BA0, LOW);

  if(input & 0x002) digitalWrite(BA1, HIGH);
  else  digitalWrite(BA1, LOW);

  if(input & 0x004) digitalWrite(BA2, HIGH);
  else  digitalWrite(BA2, LOW);

  if(input & 0x008) digitalWrite(BA3, HIGH);
  else  digitalWrite(BA3, LOW);

  if(input & 0x010) digitalWrite(BA4, HIGH);
  else  digitalWrite(BA4, LOW);

  if(input & 0x020) digitalWrite(BA5, HIGH);
  else  digitalWrite(BA5, LOW);

  if(input & 0x040) digitalWrite(BA6, HIGH);
  else  digitalWrite(BA6, LOW);

  if(input & 0x080) digitalWrite(BA7, HIGH);
  else  digitalWrite(BA7, LOW);

  if(input & 0x100) digitalWrite(BA8, HIGH);
  else  digitalWrite(BA8, LOW);

  if(input & 0x200) digitalWrite(BA9, HIGH);
  else  digitalWrite(BA9, LOW);

}

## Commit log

2025-06-09 DPS update
    [286.kicad_sch]
2025-06-09 PCB update
    [286.kicad_sch]
2025-06-16 PAL decoding
    [286.kicad_sch]
2025-06-25 schematic update
    [286.kicad_sch, Memory.kicad_sch]
2025-06-28 schematics update
    [286.kicad_sch, CPU_ChipSet1.kicad_sch, CPU_ChipSet2.kicad_sch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]
2025-07-03 Added IDE controller reverse eng
    [IDE_controller.kicad_pcb, IDE_controller.kicad_sch]
2025-07-03 IDE controller update
    [IDE_controller.kicad_pcb, IDE_controller.kicad_sch]
2025-07-05 IDE controller update + decoder
    [IDE_controller.kicad_pcb, IDE_controller.kicad_sch]
2025-07-11 commit from lucky
    [CPU_ChipSet1.kicad_sch, FLOPPY_IDE.kicad_sch]
2025-07-21 286 sch updates
    [CPU_ChipSet1.kicad_sch, ChipSet2.kicad_sch]
2025-07-28 BIOS captured by logic analyser
    [capture00.csv]
2025-07-29 BIOS anasyse
    [capture00.csv]
2025-08-03 BIOS 1234 test
    [capture00.xlsx]
